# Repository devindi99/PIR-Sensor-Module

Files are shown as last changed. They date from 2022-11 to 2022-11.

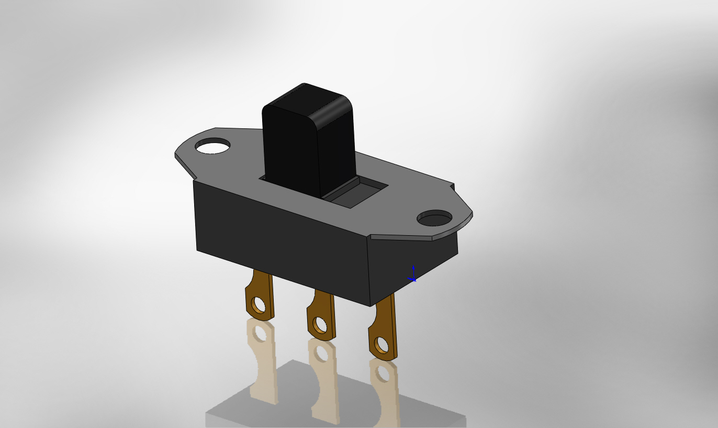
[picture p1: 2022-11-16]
enclosure/Renderings/SW338-ND.JPG

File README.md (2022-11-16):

# PIR-Sensor-Module
The Passive Infra-Red (PIR) sensor module detects IR emitting
objects within a certain range. The module consists of:
1. RE200b PIR sensor
2. Resistors
3. Capacitors
4. Operational amplifiers
5. Potentiometers
6. Switches
7. Buzzer and/or lamp. 

The characteristics
of the module heavily depends on the type of the IR
sensor chosen for the project i.e. whether the module can detect
both objects in motion and motionless objects in the field
of detection.
The range of the detection can be increased up to 5m, with
increments of 1m. The output of the module is given by the
buzzer and/or lamp.

The PIR sensor module has a variety of applications. For
example, the module can be used as a security device by placing
it suitably near a doorway (or passage, corridor, window,
etc.). It will detect if anyone goes through the doorway.
Also, the module can be used as an animal detection device
at night time. Especially, farmers can place some sensors
in their fields suitably, so the modules may detect if there are
animals in the field and emit bright light or give out a repelling
sound, which will scare away animals.

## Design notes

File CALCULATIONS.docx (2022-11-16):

High Cut Off=1/(2πR_1 C_1)

F_H =1/(2π×500K×10n)

F_H =31.83O9 Hz

Gain=(R_1)/(R_2)

G1=(500K)/(10K)

G1=50

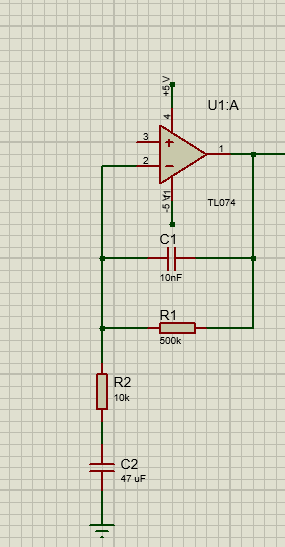
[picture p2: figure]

Low cutoff = 2.1276Hz

High Cut Off=1/(2πR_4 C_4)

F_H =1/(2π×3M×10n)

F_H =5.3051 Hz

Low Cut Off=1/(2πR_3 C_3)

F_L =1/(2π×10k×10u)

F_L =1.5915 Hz

Gain=(R_4)/(R_3)

G2=(3M)/(10K)

G2=300

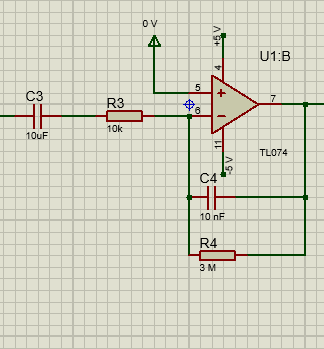
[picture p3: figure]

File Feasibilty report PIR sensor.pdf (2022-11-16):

Feasibility Report | Group 06

### 1. ABOUT THE SENSOR

The PIR sensor detects the change in level of IR radiations. For this purpose, we will be using RE200B as the PIR sensor. It comes with two balanced sensors/ IR detectors which are covered with a hermetically sealed metal can to improve noise/temperature/humidity immunity. The window made of IR-transmissive material lets IR waves pass

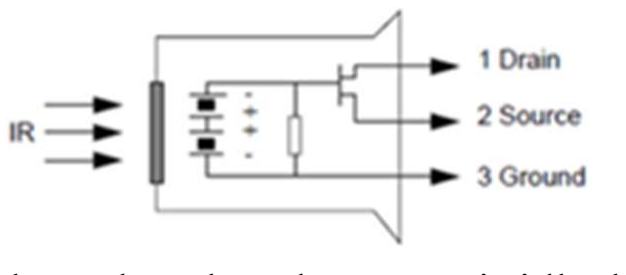
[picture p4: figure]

through. When the sensor is idle, both slots detect the same amount of IR. When a warm body passes by, it first intercepts one half of the PIR sensor and the level of IR radiation of that half rises more than the other half, which causes a positive differential change between the two halves. When the warm body leaves the sensing area, the reverse occurs, and the sensor generates a negative differential change. It is then converted to a useful signal voltage by a JFET or an OpAmp.

Note: When a pyroelectric layer interacts with IR radiation, it heats up and surface charge rises and when the radiation is switched off, a charge of opposite polarity originates.

### 2. MODES OF OPERATION

There are 2 modes of operation in the PIR sensor.

### 1. Single Trigger Mode 2. Repeat Trigger Mode

We can choose which mode to use depending on the purpose when needed.

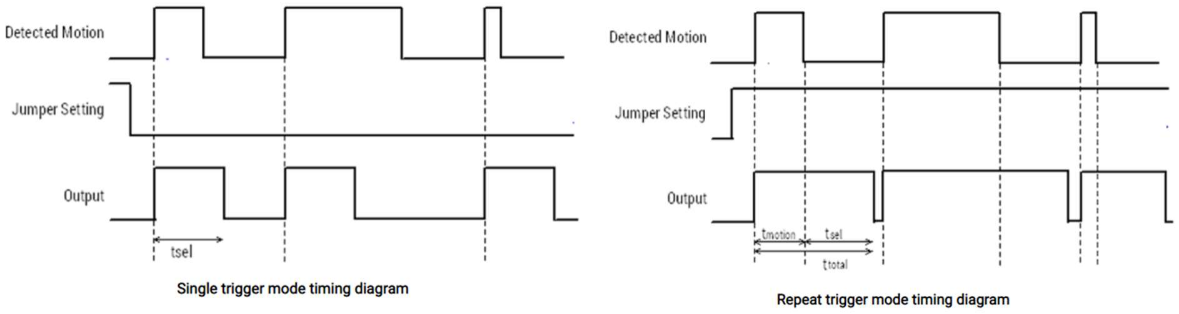
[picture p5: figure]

### 2.1 Single Trigger Mode

To select Single Trigger mode, the jumper setting on the PIR sensor must be set on LOW. In this mode output goes HIGH when motion is detected. After a specific delay the output goes to LOW even if the object is in motion. The output is LOW for some time and again goes HIGH if the object remains in motion. This delay is provided by the user using the potentiometer.

### 2.2 Repeat Trigger Mode

To select Repeat Trigger mode, the jumper setting on the PIR sensor must be set on HIGH. In case of Repeat Triggered Mode, output goes HIGH when motion is detected. The output of the PIR sensor is HIGH until the object is in motion. When an object stops motion, or disappears from the sensor area, the PIR continues its HIGH state up to some specified delay. We can provide this delay by adjusting the potentiometer.

Feasibility Report | Group 06

### 3. RANGE ADJUSTMENT OF THE SENSOR

### 3.1 Lens

To collect and focus IR radiation from the field of sensing, a Fresnel lens is used which is made up of IR transmissible material. The advantages of Fresnel lens over typical concave or Plano-concave lens are low weight, low IR absorption by the lens material, low price and less space for the lens.

### 3.2 Range

As the proximity of the detecting object determines the amount of IR collected by the lens, the voltage produced by the IR sensor varies. If the minimum voltage requirement for optimum operation is V, different ranges; 1m – 2m, 2m – 3m, 3m – 4m, 4m – 5m could be distinguished by connecting a potentiometer in series with the IR sensor to bring down the generated voltage to V and tuning it for the required range. The resistance values for different ranges are pre-determined by trial-and-error method.

### 4. CHANGING SENSITIVITY AND DELAY TIME

There are two potentiometers on PIR motion sensors board for sensitivity adjustment and time delay adjustment.

### 5. VOLTAGE REGULATION

The PIR sensor is powered from the 230V main supply, which is AC, but the PIR sensor operates in an input DC voltage in range 4.5V to 20V. We have planned to design our PIR sensor in such a way that it can be operated in 5V input voltage. So, we must step down the input AC supply, rectify it and finally regulate it to 5V to be supplied to our sensor. We have planned to use an appropriate step-down transformer, bridge rectifier IC and a 7805-voltage regulator IC for those purposes respectively.

### 6. LIGHT SENSITIVITY

The PIR sensor we design must work only in night or low light conditions. So, for this purpose we must sense the light of the environment and design our sensor in such a way that it works only when the intensity of light is lower than some threshold value. In order to do this, we have to sense the light intensity of the environment and we have planned to use a simple LDR (Light Dependent Resistor) to work this out.

### 7. INDICATING THE OUTPUT STATE

Buzzer and lamp both will be used to show the output state and the user can choose any one of them or both according to their application.

### 8. MANUFACTURING THE PCB

PCB will be manufactured by external sources. We are planning to use double layer since it will make the PCB much smaller.

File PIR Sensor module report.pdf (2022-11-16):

## UNIVERSITY OF MORATUWA

## DEPARTMENT OF ELECTRONIC AND TELECOMMUNICATION

## ENGINEERING

# EN2090 - Laboratory Practice - II

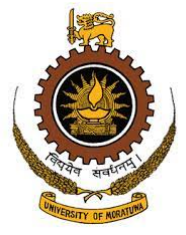
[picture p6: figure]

## PIR Sensor Project Report

Name | Index number
D. M. S. S. Dassanayake | 190115P
W. A. D. K. De Silva | 190128H
J. V. A. P. Dilshan | 190144D
A. G. Diron | 190149X

May 07 2022

## Contents

1 | Introduction | 1
2 | Functionality | 1
3 | Result | 6
4 | Discussion | 6
5 | Referenes | 7
6 | Contributions | 7
7 | Appendices | 8

ABSTRACT

The main goal of this project was to create a sensor module that can detect human motion. Mainly filtering and amplification was done to achieve this requirement. User Interface, power supply, sensitivity to light intensity, input block, timer adjustment circuit and the distance adjustment circuit are the main parts of the project. In the final evaluation human motion was successfully detected.

### 1. INTRODUCTION

The Passive Infra-Red (PIR) sensor module detects IR emitting objects within a certain range. The module consists of an PIR sensor, resistors, capacitors, operational amplifiers, potentiometers, switches, and buzzer and/or lamp. The characteristics of the module heavily depends on the type of the IR sensor chosen for the project i.e. whether the module can detect both objects in motion and motionless objects in the field of detection.
The range of the detection can be increased up to 5m, with increments of 1m. The output of the module is given by the buzzer and/or lamp.
The PIR sensor module has a variety of applications. For example, the module can be used as a security device by placing it suitably near a doorway (or passage, corridor, window, etc.). It will detect if anyone goes through the doorway. Also, the module can be used as an animal detection device at night time. Especially, farmers can place some sensors in their fields suitably, so the modules may detect if there are animals in the field and emit bright light or give out a repelling sound, which will scare away animals.

### 2. FUNCTIONALITY

### 2.1. Components used

- RE200B sensor
- LDR
- 7805, 7905 Voltage regulators
- 50k, 100k potentiometers
- TL074 opamps
- SN74HC08N IC
- Resistors - 100Ω, 220Ω, 1kΩ, 2kΩ, 10kΩ, 47kΩ, 100kΩ, 1MΩ, 2MΩ
- Capacitors - 10nF, 100nF, 10µ F, 47µ F, 100µ F
- BC547, BC557 Transistors
- LED
- Two way switch
- 1N4007 Diodes
- Fresnel Lense
2.1.1. RE200B sensor

RE200B is the PIR sensor used for this project. This sensor can only detect IR emitting objects that are in motion. For the same reason, the PIR sensor module also detects only the IR emitting objects in motion. The RE200B has a detection angle of 138 degrees.
The IR sensors are placed inside a hermetically sealed metal can to improve noise/temperature/humidity immunity. The window made of IR-transmissive material protects the sensing element. There are two balanced sensors behind the window.

Fig. 1. RE200B Sensor

When the sensor is idle, both IR sensors detect the same amount of IR. When a warm body passes by, it first intercepts one half of the PIR sensor, which causes a positive differential change between the two slots. When the warm body leaves, the reverse happens, where the sensor generates a negative differential change. This voltage difference is taken as the output of the PIR sensor. The maximum variation of the output is 20 mV (peak to peak).

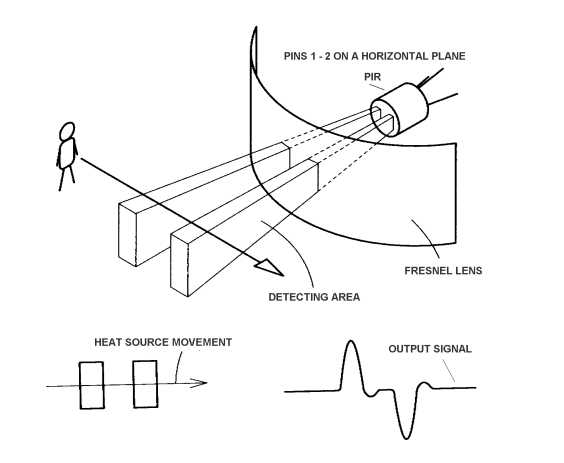
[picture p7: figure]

Fig. 2. Output of the sensor

2.1.2. LDR

Light Dependent Resistor (LDR) consists of a semiconductor material that will change its resistance from several thousands of ohms in the dark to a few hundred ohms when exposed to light. Hence this component is used as a lighting switch in the PIR sensor module.

Fig. 3. LDR

2.1.3. Voltage Regulators

In order to provide power for the op-amps and the RE200B sensor we need +5V and -5V power supply. To obtain this we use a 7805 voltage regulator together with a 7905 voltage regulator. The 7805 regulator stabilizes a +5V constant voltage output and 7905 stabilizes a constant -5V voltage for a variable input supply.

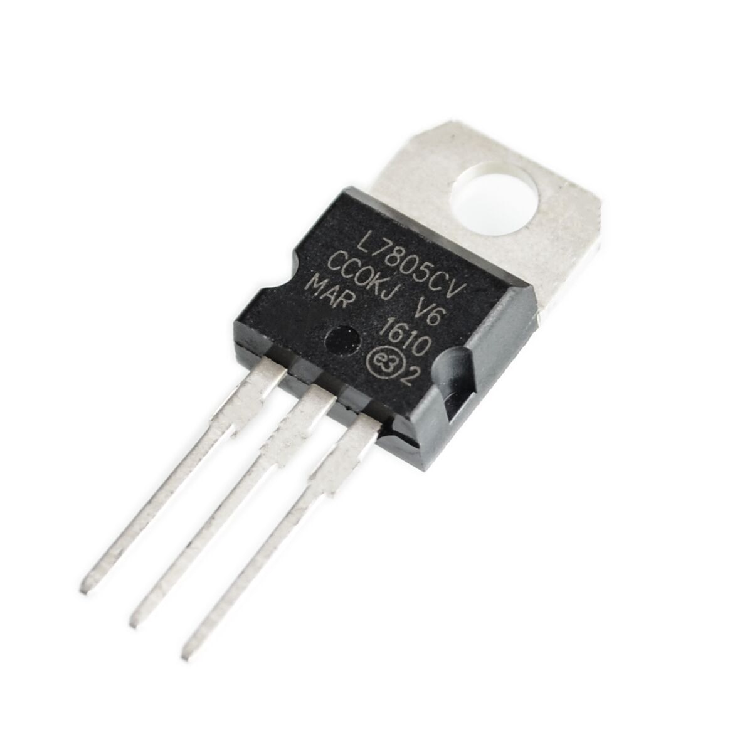
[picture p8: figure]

(a) 7805 | (b) 7905

Fig. 4. Voltage regulators

2.1.4. TL074CN

TL074 IC consists of 4 high-speed JFET input single operational op-amps. This device has high slew rate of 16 V/µs low input bias and offset currents. This op-amps are used in the circuit to obtain a low-pass filter, band-pass filter, comparator circuits and as a buffer circuit.

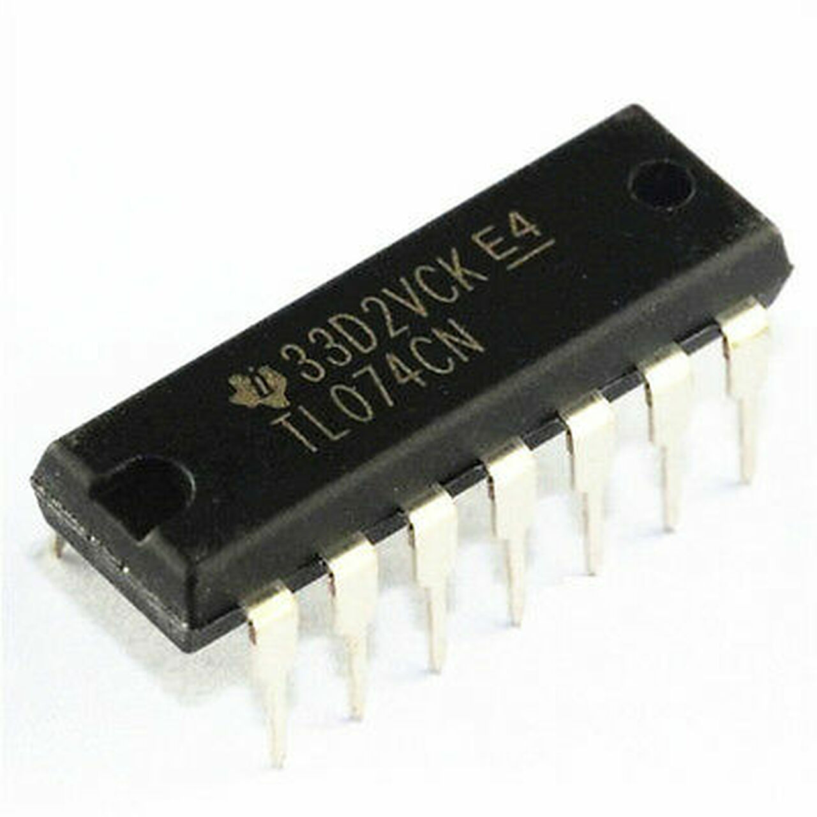
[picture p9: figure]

Fig. 5. TL074CN

2.1.5. SN74HC08N

This device contains four independent 2-input AND gates. This IC is used as a buffer when combining the Light sensitivity circuit and timer circuit with the distance adjustment circuit.

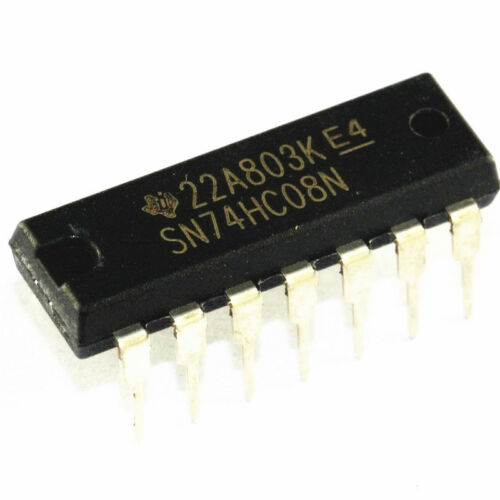
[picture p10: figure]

Fig. 6. SN74HC08N

2.1.6. Fresnel Lense

To collect and focus IR radiation from the field of sensing, a Fresnel lens is used that is made up of IR transmissible material. The advantages of Fresnel lens over typical concave or Plano-concave lens are; low weight, low IR absorption by the lens material, low cost and less space for the lens. Most importantly, the sensitivity of the sensor is increased by the Fresnel lens. If an object is to be detected; the IR rays detected

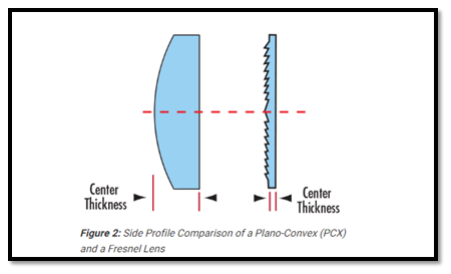
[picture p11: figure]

Fig. 7.

by one of these sensor slots should be relatively higher than the other sensor slot. As there are only two sensor slots, an object moving in the non-sensing area (area between the two sensor slots) may not be detected if the motion of the object is such that it does not cross any of the sensor slots. This kind of motion can happen in further distances as the gap between the two sensor slots are increased. In order to avoid such scenarios, the honeycomb structure lens cap is used. Honeycomb structure lens caps split the two sensor fields into many sensor fields, thus reducing non-sensing areas between sensor fields. This special lens cap also increases the sensor angle of the sensor.

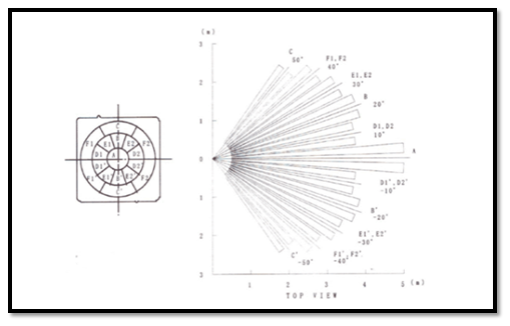
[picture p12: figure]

Fig. 8.

### 2.2. Methodology

2.2.1. Power supply

The sensor is powered from the 230V main supply. A center tapped transformer(24V) is used to step down the voltage. To get a stabilized +5V and -5V, 7805 and 7905 regulators are used. Two heat sinks are used with the regulators to prevent damage at high temperatures.

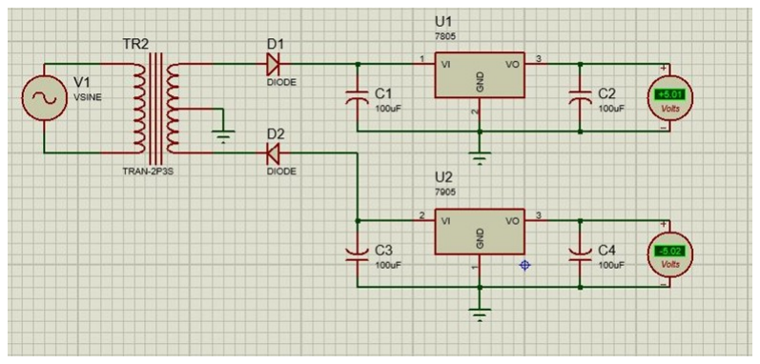
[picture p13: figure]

Fig. 9. Power regulation circuit

2.2.2. Light sensitivity Control

The module is designed in a way such that it works only under night/low light conditions. A simple LDR is used to achieve this. LDR has a high resistance of nearly 100 kΩ when it is in dark and has low resistance of nearly 5 kΩ when exposed to light. This simple principle of LDR is used to achieve the sensitivity of the module to light intensity. . An op-amp comparator circuit is used with 10 kΩ as the resistor on the other side for this purpose with the other input terminal of the op-amp is connected to the GND as shown in the figure. This comparator gives +5V as the output in night/low light and -5V as the output in bright light.
The comparator output is fed to an AND gate with the other terminal of the gate given a fixed value of +5V. This AND gate is used as a buffer circuit to supply power to the sensor circuit. The functionality of the AND gate is shown in the below table.

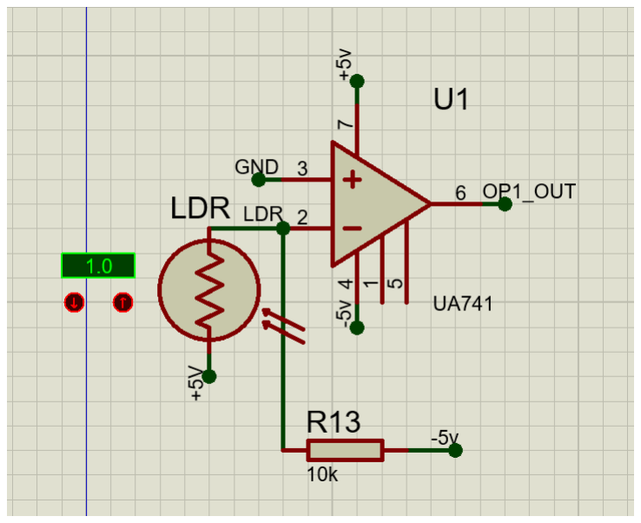
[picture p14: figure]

Fig. 10. Light sensitivity Control circuit

Condition | AND gate Inputs | Status
Bright | +5V +5V | ON
Low | -5V +5V | OFF

As in the table the sensor module works only in night/low light conditions.

2.2.3. Taking the input from PIR sensor

The voltage output of the RE200B sensor is fed through a active low pass filter to cancel out the noise.

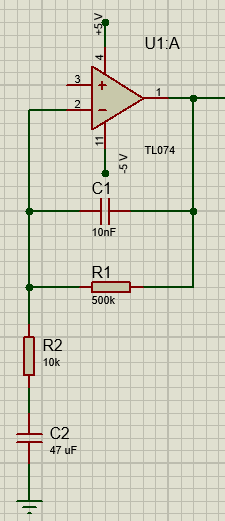
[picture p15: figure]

Fig. 11. Low Pass filter

Cutoff frequency =

1
2πR1C1

F1 =

1
2π ∗ 500kΩ ∗ 100nF
= 31.8309Hz

(1)

The filter has a gain of:

Gain =

R2
R1

G1 =

500kΩ
10kΩ
= 50

(2)

Then output of the low pass filter is fed through a bandpass filter.

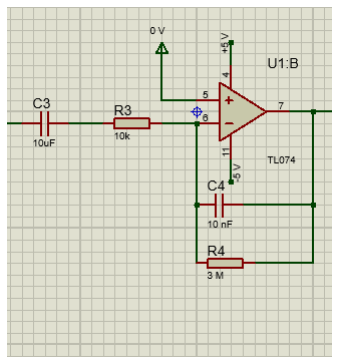
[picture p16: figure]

Fig. 12. Band Pass filter

High cutoff frequency =

1
2πR4C4

FH =

1
2π ∗ 3MΩ ∗ 10nF
= 5.3051Hz

(3)

Low cutoff frequency =

1
2πR3C3

FL =

1
2π ∗ 10kΩ ∗ 10µF
= 1.5915Hz

(4)

The filter has a fixed gain of:

Gain =

R4
R3

G1 =

3MΩ
10kΩ
= 300

(5)

Total gain of the circuit is 50*300 = 15000

2.2.4. Range adjustment

Range is achieved by controlling the gain of the 4

th amplifier used in the module. Higher the gain, higher will be the range. This is because, with higher gain, the slightest variation in the output of RE200B is amplified enough to get detected resulting increase in range, and with lower gain, those slight changes are too insignificant to get detected resulting decrease in range. Gain controlling is achieved with a suitable potentiometer. By trial and error method, the appropriate gain values for various ranges up to 5m with 1m increments are found. It is done by controlling the resistance of the potentiometer which then controls the gain.

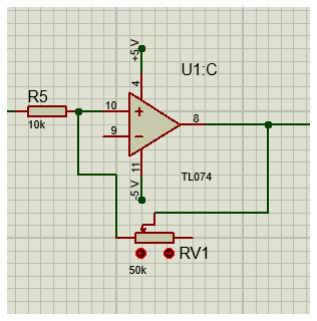
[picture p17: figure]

Fig. 13. Range adjustment

The potentiometer resistance values corresponding to the maximum sensing distance is shown in the below table.

Max. distance (m) | Resistance (kΩ) (±0.7)
1 | 3.78
2 | 10.33
3 | 13.6
4 | 20.3
5 | 24.7

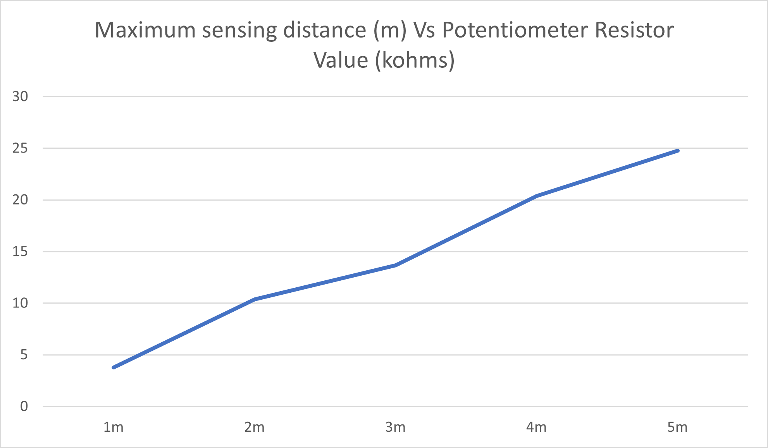
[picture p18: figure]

Fig. 14. Range calibration

2.2.5. Taking the digital output

The digital output is obtained by using two comparator circuits and a simple OR gate (build using 1N4007 diodes). The threshold values are set to +1.25V and -1.25V. Therefore whenever the voltage value goes beyond the threshold values the comparator circuit outputs +5V. This is connected to the timer circuit through an AND gate similar to the connection of light sensitivity circuit and sensor circuit. The threshold values are selected in order to increase the probability of detecting a motion and avoid unwanted reaction of the sensor module.

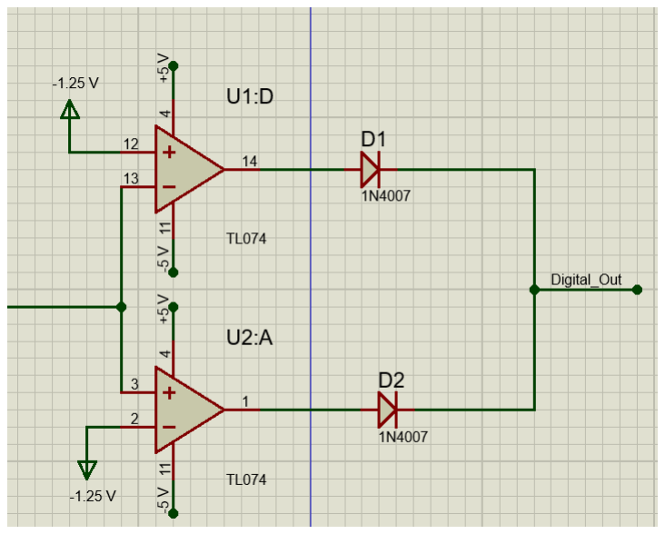
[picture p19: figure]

Fig. 15. Digital output

2.2.6. Timer adjustments

The module can work under two modes
- Single Trigger mode
- Repeat Trigger mode
These modes can be changed using a switch.

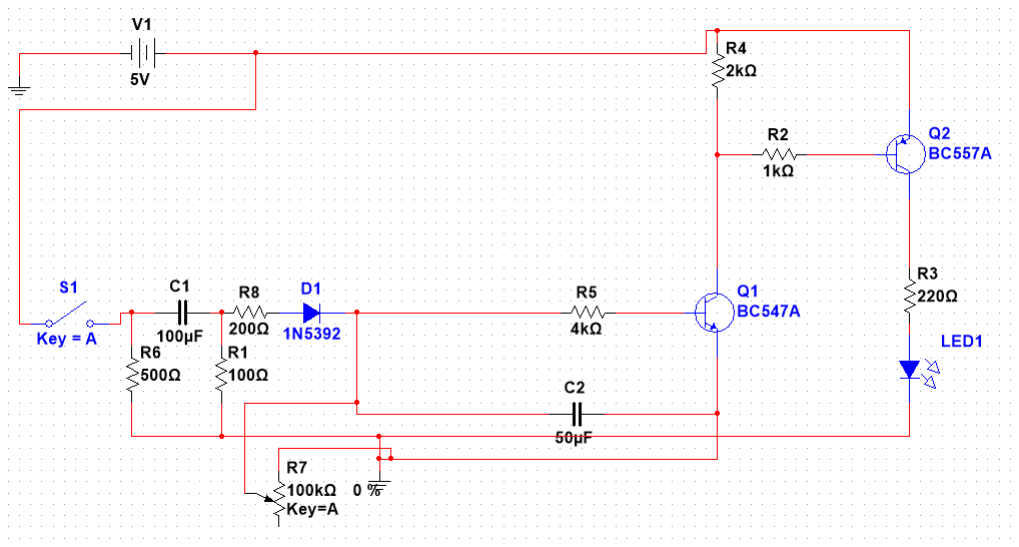
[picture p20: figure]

Fig. 16. Timer circuit

Single Trigger mode

In this mode the LED lights up when motion is detected. After a specific delay the LED goes off even if the object is in motion. The specific delay can be changed using a potentiometer.
This mode can be achieved by switching S1 down. After activating this mode, both capacitors C1 and C2 begin to charge. The R1 (100 Ω) resistor helps the C1 capacitor to charge quickly. When capacitor C1 is fully charged (when the voltage across capacitor C1 becomes 5V), the current flowing through the circuit stops. At this point the C2 capacitor is charged to a level that can forward bias the BE junction of the Q1 transistor. It moves the Q1 transistor to the saturation mode. The VCE of Q1 decreases and it makes the BE junction of Q2 transistor forward bias and it saturates Q2. It illuminates the LED. Once C1 is fully charged, C2 capacitor begins to discharge through the variable resistor R7. Diode D1 blocks the discharging current flowing through the left side of the circuit. Transistor Q1 goes to cut off mode when the voltage drop across capacitor C2. It cuts off the Q2 transistor and turns off the LED. The specific delay of the single trigger mode can be changed by changing the discharge time of the C2 capacitor. This can be achieved by changing the R7 resistance.

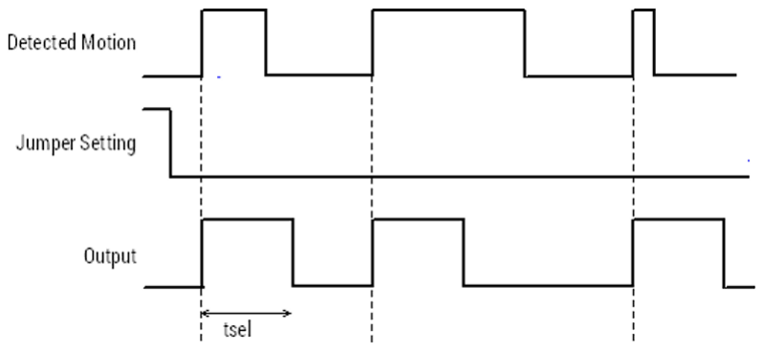
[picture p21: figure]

Fig. 17. Single Trigger mode

Repeat Trigger mode

In this mode, the LED lights up when motion is detected. The LED is ON until the object is in motion. When an object stops motion, or disappears from the sensing area, the LED stays ON for some specific delay. The specific delay can be changed using a potentiometer.
This mode can be achieved by switching S1 up. After activating this mode, C2 begins to charge. This drives the Q1 transistor to saturation. As in the previous mode the Q2 transistor becomes saturated and the LED lights up. When an object stops motion, or disappears from the sensing area, the C2 capacitor begins to discharge through the variable resistor R7. During the discharge time (until Q2 becomes cut off) the LED stays ON for some specific delay. In here Diode D1 separates the left side and the right side of the circuit. As in the previous mode the transistor Q1 goes to cut off when the voltage drops across capacitor C2. It cuts off the Q2 transistor and turns off the LED. The specific delay of the repeat trigger mode can be changed by changing the discharge time of the C2 capacitor. This can be achieved by changing the R7 resistance.

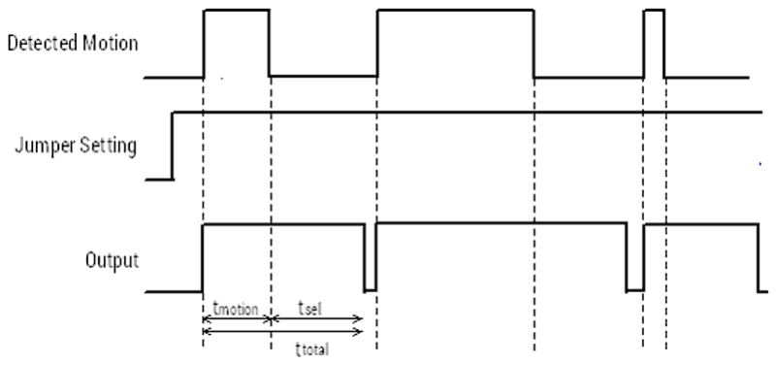
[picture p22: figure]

Fig. 18. Repeat Trigger mode

2.2.7. Indicating the output

The output of the module is shown using a LED attached to the enclosure. The indicator can be replaced with a buzzer circuit as well as per the wish, since the indicator is connected using a connector to the PCB. According to the preference of the user the indication can be given as light through a LED or as sound using a buzzer circuit as well.

### 3. RESULT

### 3.1. Prototype Description

The prototype is supposed to detect any motion in its sensing range in night/low light conditions and give an LED output. Its maximum sensing distance can be changed using a potentiometer. The built prototype was tested inside the laboratory manually under several circumstances and performed as expected.

### 3.2. PCB Design

PCB for the project was designed using the Altium Designer software version 21.3.1. The PCB designed for the project is a double layer PCB of dimension 98.806mm x 62.484mm. The PCB was manufactured by a local manufacturer. The normal traces are 0.8mm and +5V, -5V traces are 1mm in width. The GND is the copper plane. The clearance between traces is 0.8mm. The design of the PCB is shown below.

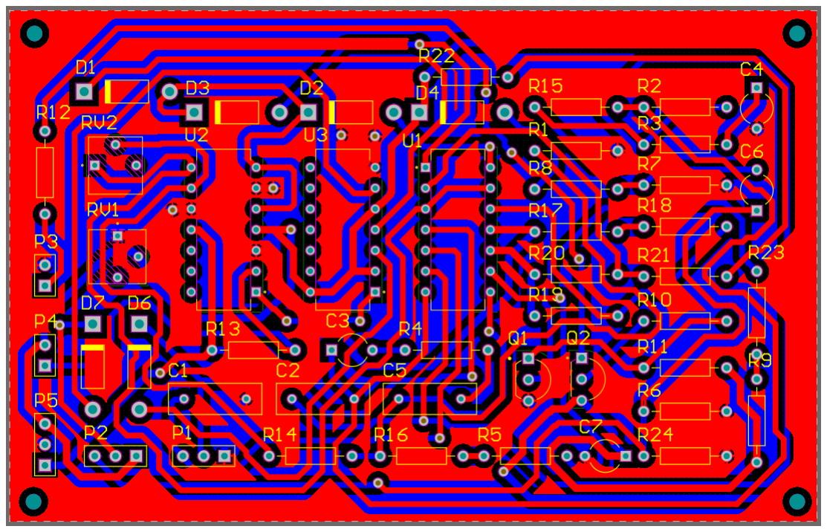
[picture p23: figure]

Fig. 19. PCB design

### 3.3. Enclosure design

The enclosure was designed using dark gray high gloss plastic. The RE200B sensor is placed inside a fresnel lens. Two plastic knobs are attached to the enclosure to control the two potentiometers. A toggle switch is used to switch between the timing modes.

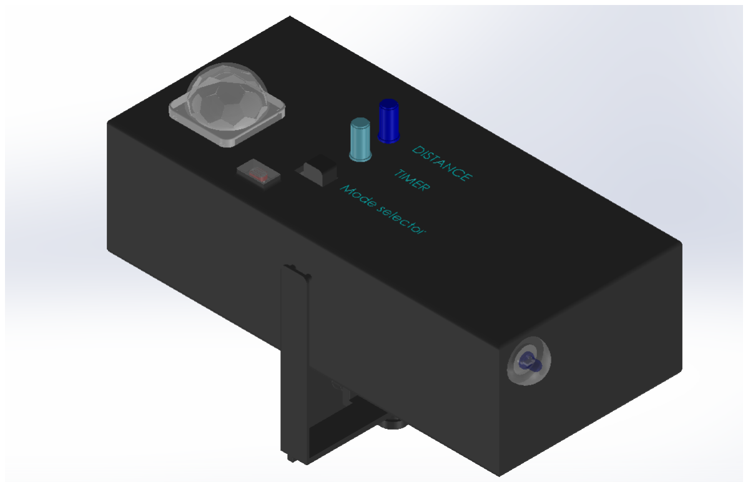
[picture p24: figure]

Fig. 20. Enclosure design

### 4. DISCUSSION

### 4.1. PCB Manufacturing and soldering

Designing the PCB was a bit challenging as it is required to route all the pins of the ICs in the same layer in order to make soldering of the IC easier. To meet that requirement many vias were used.
After manufacturing the PCB only, a mistake on the schematic of the circuit is found. So, the mistakes were found and re routed manually using wires. For manufacturing, the PCB is mirrored so the component pins are mismatched in the manufactured PCB. So the pins of some components had to be inverted especially for the ICs to match the correct pins with the footprints. Due to these, soldering the components was challenging. The final manufactured PCB after soldering the components looked like as shown in the below figure.

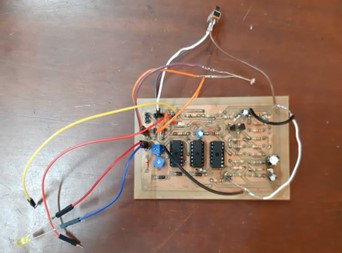
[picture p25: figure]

Fig. 21. Final PCB

### 4.2. Enclosure designing

The LED is placed in such a way that the emitted light is not detected as a bright light condition by the LDR.

### 4.3. Prototype designing

This project was really helpful to learn how a PIR sensor works. Using the knowledge in the analog electronics the analog output from the PIR sensor was converted as the digital output required to indicate using an LED. As mentioned above soldering the PCB was the most challenging part of the project. Apart from that in the breadboard implementation the circuit sometimes did not work as expected due to some loose connections making it hard to debug the circuit. Therefore we had to debug the circuit many times to get the final prototype as the result.
The skill of using the laboratory equipment and knowledge about some electronic components are improved with the help of this project. Other than that everyone learnt how to work on the project in a given timeline, working as a team and managing the work load of the project together with the other things to do. Overall this experience will help to work on the future projects in a better manner.

### 5. REFERENES

1. PIR sensor module (https://www.electronicwings.com/sensors-modules/pir-sensor)
2. RE200B datasheet (https://www.makerguides.com/wp-content/uploads/2019/07/RE200B-Datasheet.pdf)
3. Passive Infrared (PIR) Detector Controller (https://www.onsemi.com/pdf/datasheet/ncs36000-d.pdf)
4. TL074CN datasheet (https://bit.ly/3MZgVic)
5. SN74HC08N datasheet (https://bit.ly/3OY9dqp)

### 6. CONTRIBUTIONS

- 190115P - Distance adjustment, comparator circuit for thresholds
- 190128H - Noise cancellation, Enclosure design
- 190144D - Timer circuit, Voltage regulation
- 190149X - Light intensity circuit, PCB design


### 7. APPENDICES

### 7.1. PCB Design

(a) Top layer | (b) Bottom layer

Fig. 22. PCB design

### 7.2. Schematic diagram

Fig. 23. Schematic diagram


### 7.3. Enclosure design

(a) Top view
(b) Side view | (c) Transparent view

Fig. 24. Enclosure design

### 7.4. Datasheet



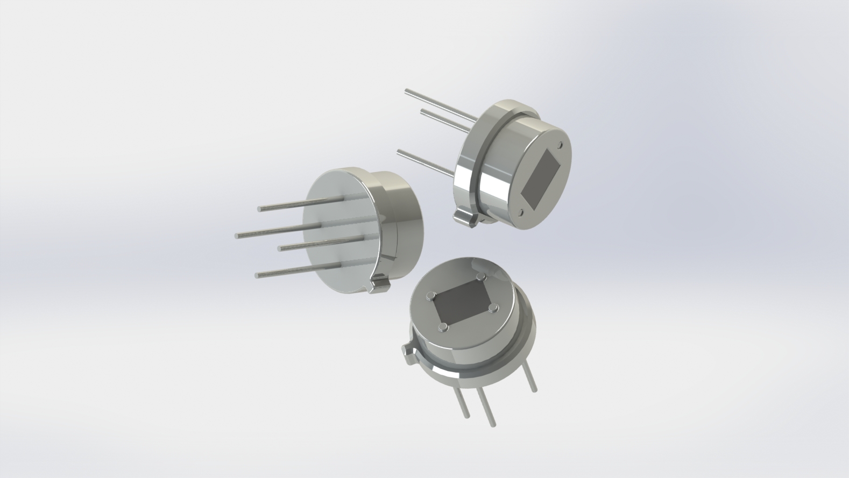
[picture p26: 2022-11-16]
enclosure/pir sensor/TO-5+1/TO-5.JPG

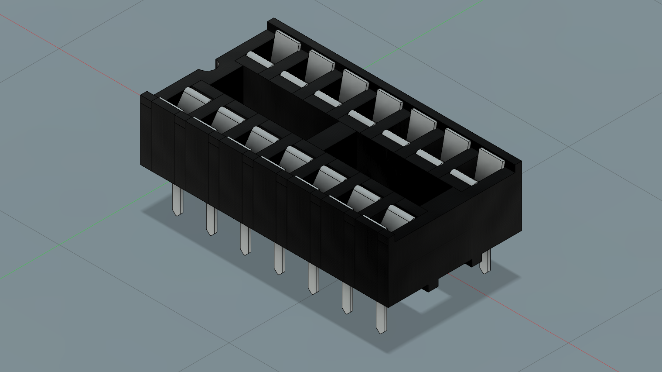
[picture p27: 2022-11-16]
enclosure/300 DIP 14 v2.png

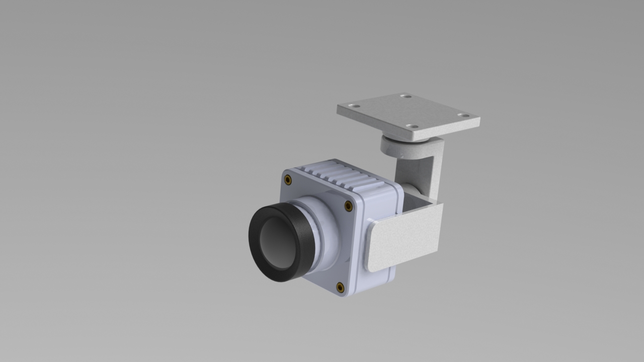
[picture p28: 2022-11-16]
enclosure/camera gimball/Untitled.JPG

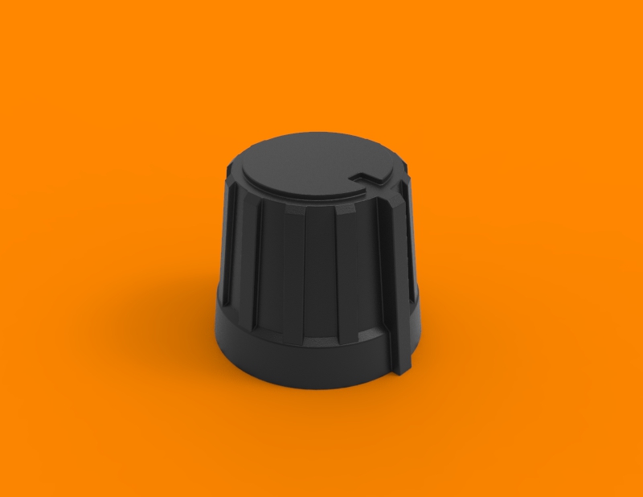
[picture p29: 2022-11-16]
enclosure/knob-103.snapshot.3 (1)/Knob.jpg

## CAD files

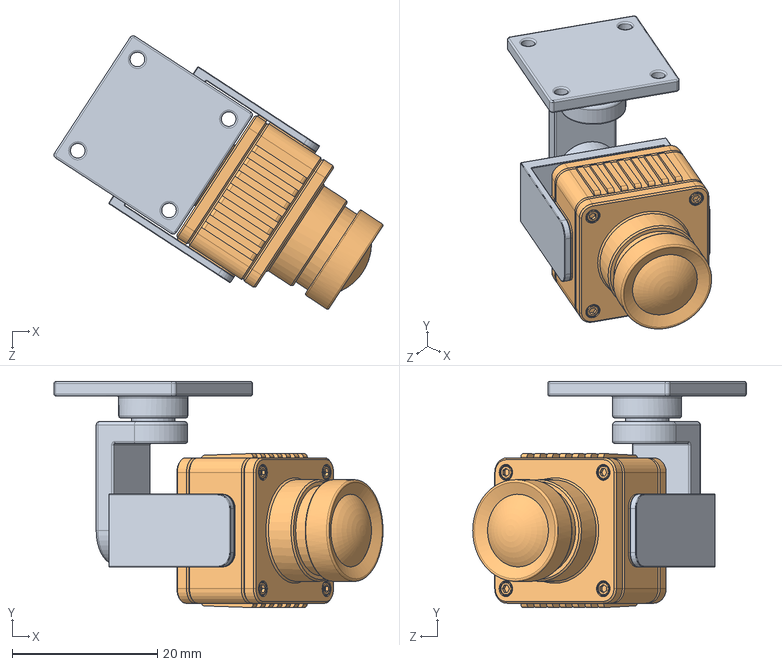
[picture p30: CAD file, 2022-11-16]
enclosure/camera gimball/camera gimbal assembly.SLDASM
45.2 x 31.1 x 37.6 mm
Camera gimball
camera DJI FPV

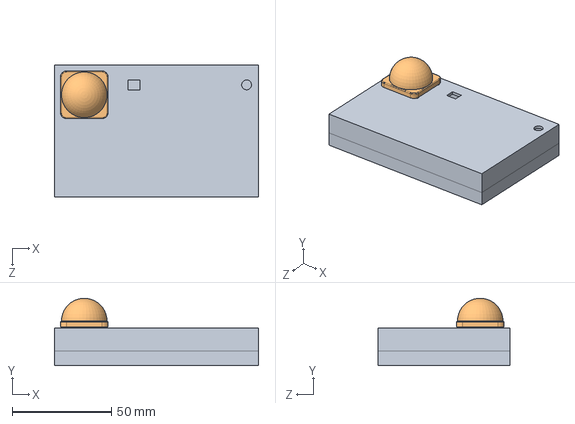
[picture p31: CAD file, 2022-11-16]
enclosure/full enclosure.SLDASM
102.8 x 34.0 x 66.5 mm
PCB enclosureSLDPRT
lens

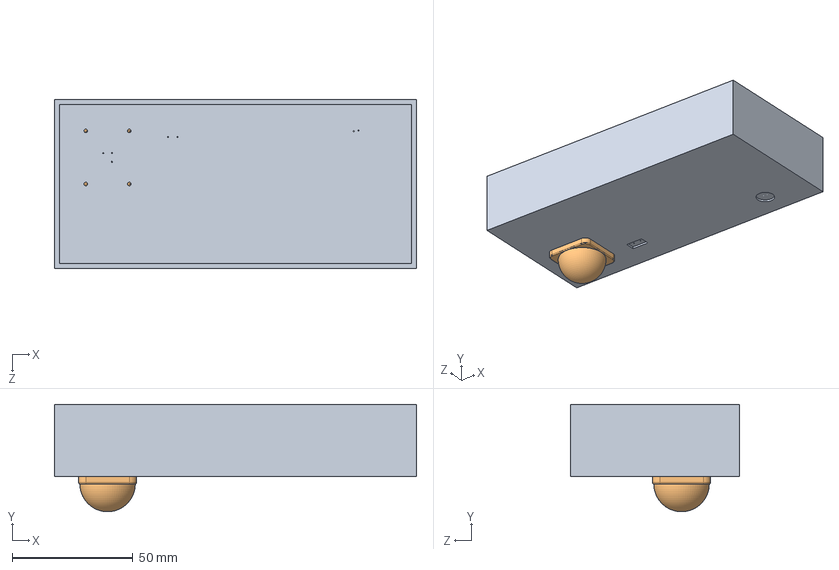
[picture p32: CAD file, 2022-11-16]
enclosure/full.SLDASM
150.0 x 44.5 x 70.0 mm
frontMudi
lens
TO-5-3pin

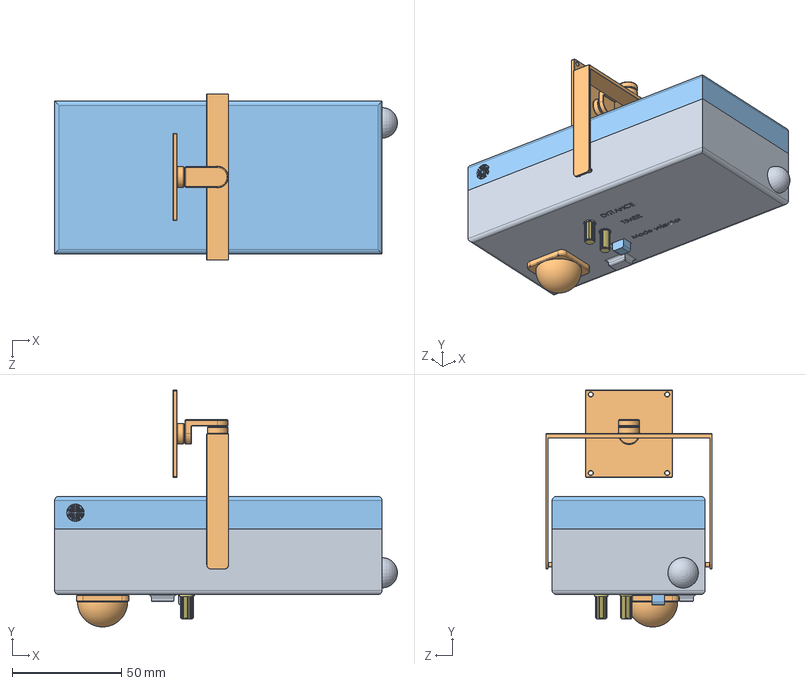
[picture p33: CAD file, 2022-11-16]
enclosure/final.SLDASM
157.0 x 108.5 x 76.0 mm
front cover
lens
back
5884946720.step
5884942880.step
knobWithScrew x 2
ldr
RE200B
Camera gimball
SW338-ND
THT LED blue glass

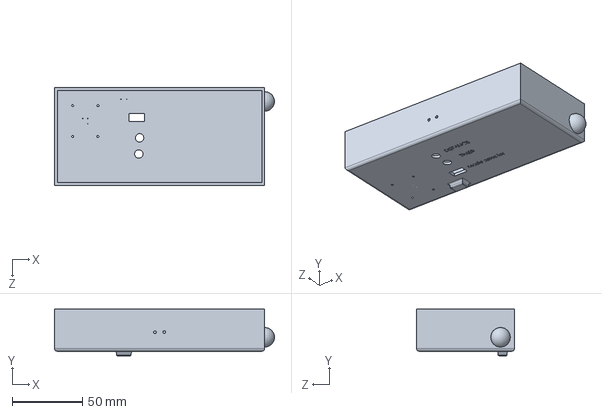
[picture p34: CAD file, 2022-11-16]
enclosure/front cover.SLDPRT
157.0 x 33.2 x 70.0 mm

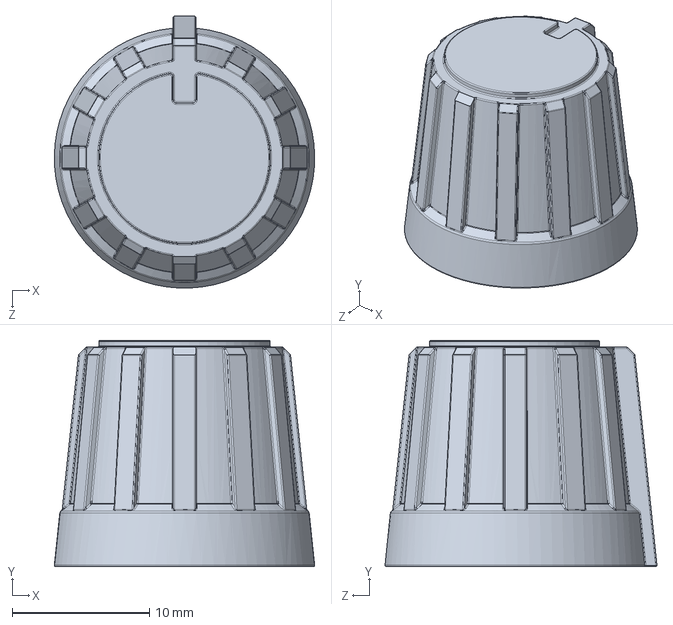
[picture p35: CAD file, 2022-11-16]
enclosure/knob-103.snapshot.3 (1)/Knob.SLDPRT
19.0 x 16.5 x 19.8 mm

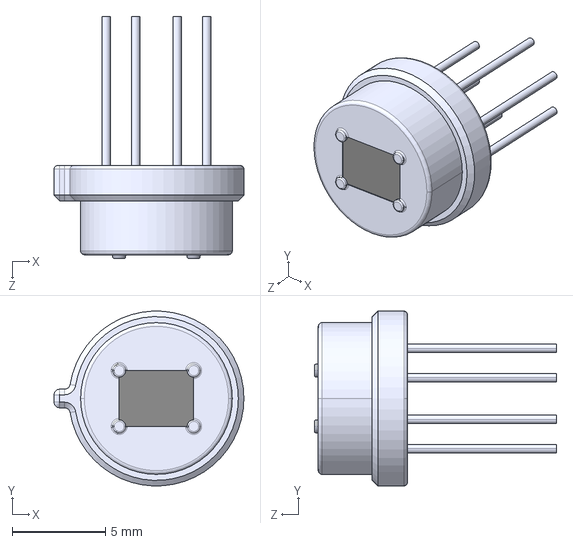
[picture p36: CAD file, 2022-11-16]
enclosure/pir sensor/TO-5+1/TO-5-6pins.STEP
10.2 x 9.39 x 13.0 mm

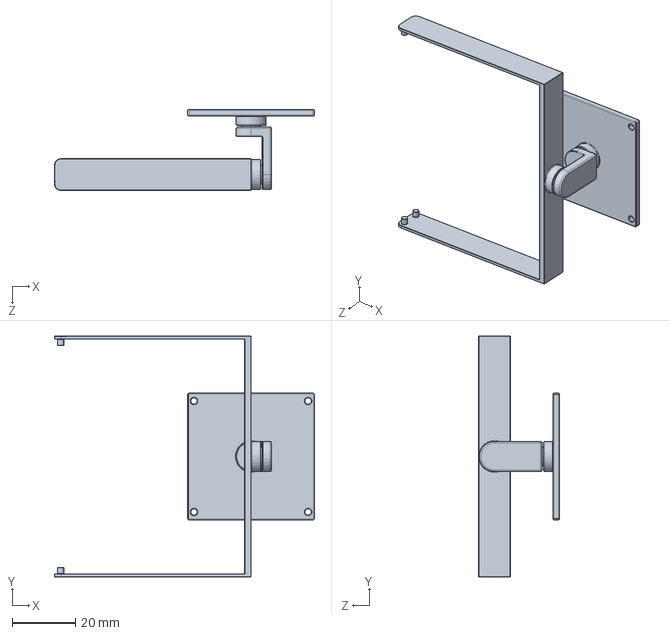
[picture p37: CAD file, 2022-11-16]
enclosure/camera gimball/Camera gimball.SLDPRT
82.0 x 76.0 x 25.5 mm

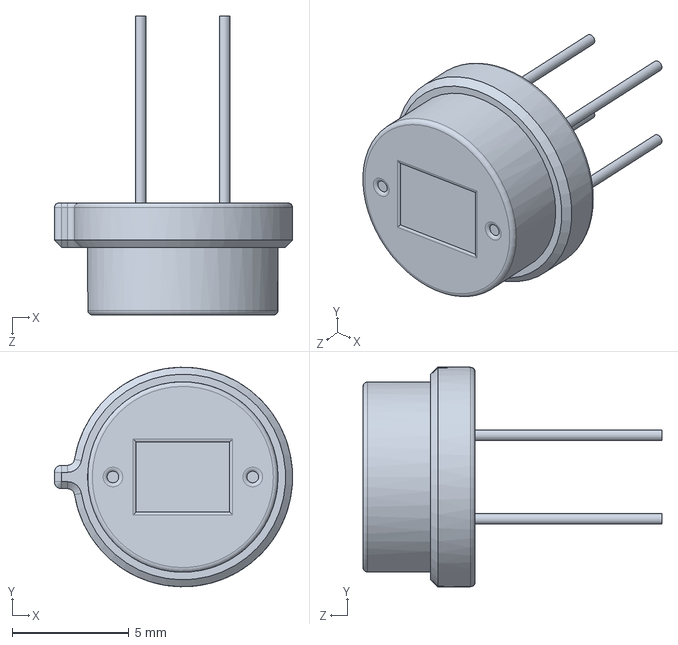
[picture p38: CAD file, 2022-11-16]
enclosure/pir sensor/TO-5+1/TO-5-4pin.SLDPRT
10.2 x 9.40 x 12.8 mm

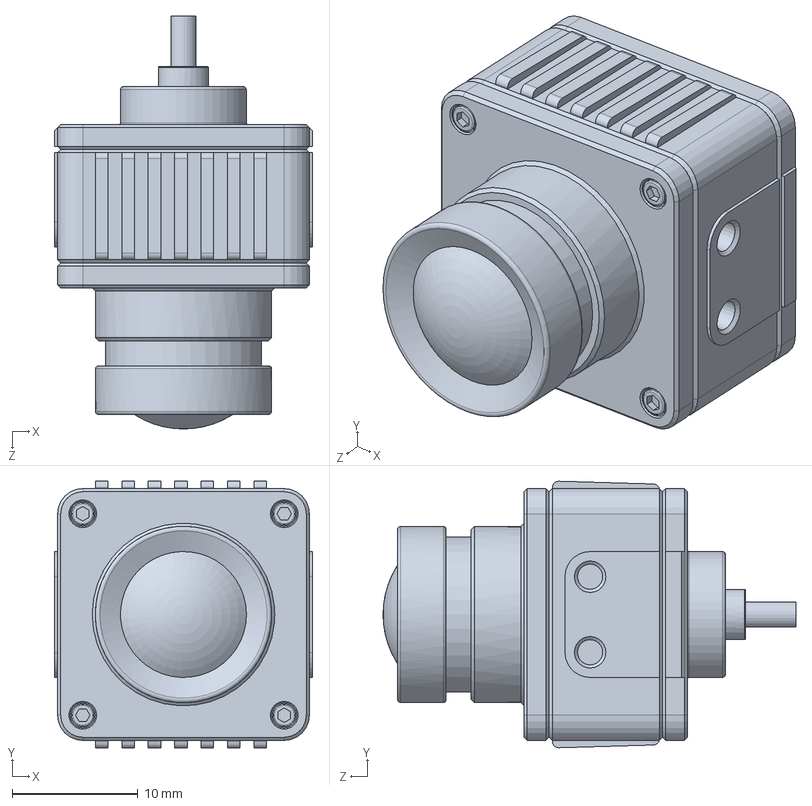
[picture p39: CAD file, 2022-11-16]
enclosure/camera gimball/camera DJI FPV.SLDPRT
20.5 x 21.2 x 32.8 mm

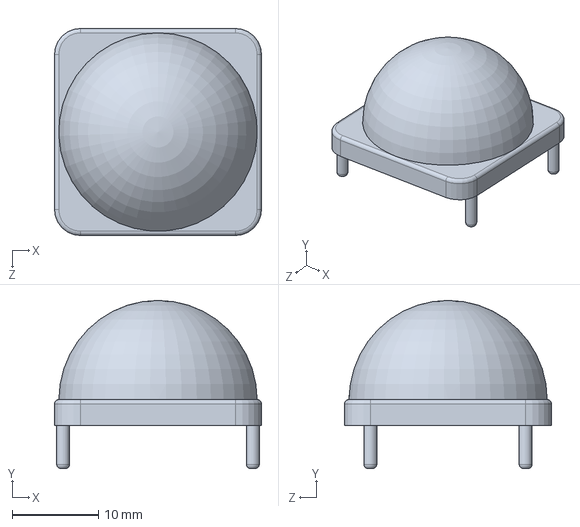
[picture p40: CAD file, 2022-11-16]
enclosure/lens.SLDPRT
24.0 x 19.5 x 24.0 mm

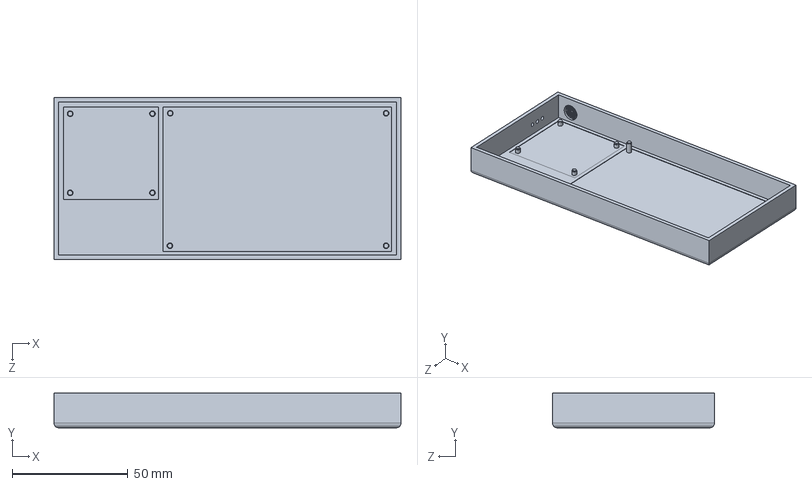
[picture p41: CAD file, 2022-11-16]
enclosure/back.SLDPRT
150.0 x 15.0 x 70.0 mm

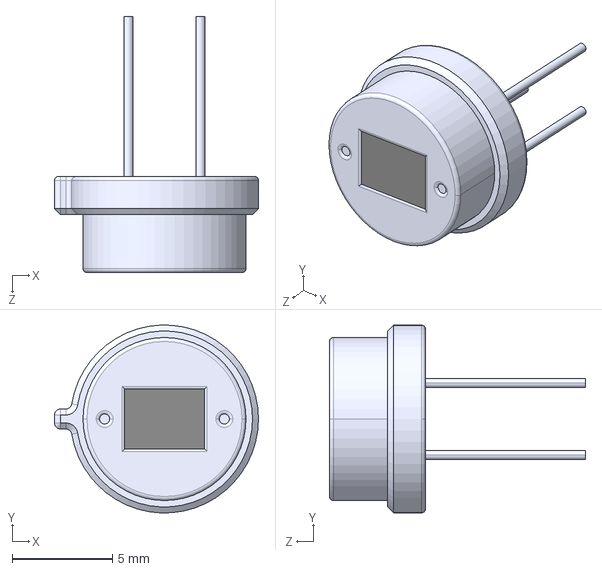
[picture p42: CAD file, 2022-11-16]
enclosure/pir sensor/TO-5+1/TO-5-3pins.STEP
10.2 x 9.39 x 12.8 mm

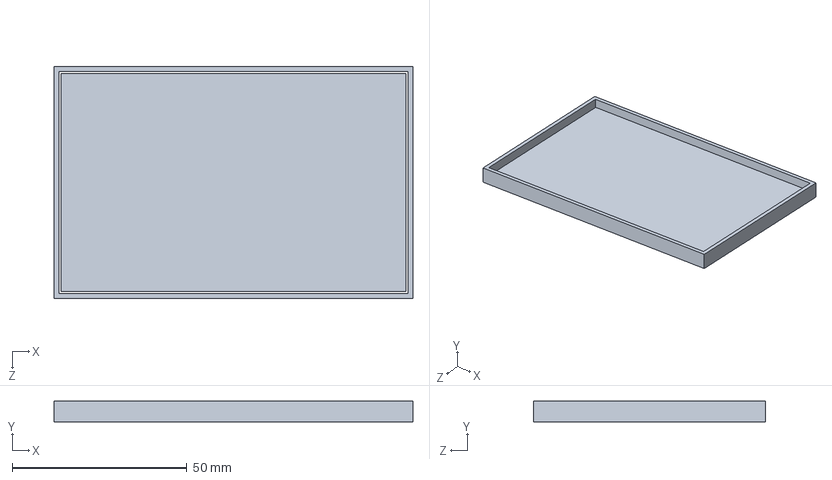
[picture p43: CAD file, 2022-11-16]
enclosure/PCB enclosureSLDPRT.SLDPRT
102.8 x 6.00 x 66.5 mm

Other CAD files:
enclosure/pir sensor/TO-5+1/TO-5-6pin.SLDPRT
enclosure/pir sensor/TO-5+1/TO-5-4pins.STEP
enclosure/pir sensor/TO-5+1/RE200B.SLDPRT
enclosure/pir sensor/TO-5+1/TO-5-3pin.DWG
enclosure/300 DIP 14 v2.f3d
enclosure/PCB_of_Schematic.step
enclosure/SW338-ND.SLDPRT
enclosure/THT LED blue glass.SLDPRT
enclosure/THT LED brown.SLDPRT
enclosure/THT LED green.SLDPRT
enclosure/knobWithScrew.SLDPRT
enclosure/ldr.SLDPRT
enclosure/pir sensor/TO-5+1/TO-5-4pin.DWG
enclosure/pir sensor/TO-5+1/TO-5-6pin.DWG

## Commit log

2022-11-16 Adding PCB design for PIR Sensor module
    [PCB_of_Schematic.PcbDoc, PIR_PCB_Project.PrjPcb, Schematic.SchDoc]
2022-11-16 Add proteus circuit designs
2022-11-16 Add solidworks file
    [300 DIP 14 v2.f3d, Camera gimball.SLDPRT, Knob.SLDPRT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]
2022-11-16 Add PCB files
    [PCB_of_Schematic.PcbDoc, PIR_PCB_Project.PrjPcb, Schematic.SchDoc]
2022-11-16 Calculations for the circuit
